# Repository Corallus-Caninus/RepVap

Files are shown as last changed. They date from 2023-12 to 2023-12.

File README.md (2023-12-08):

# RepVap
A *majority* 3D printed evaporative cooler.


A RepVap made with a 5 Gallon bucket cooling a B550M plus motherboard chipset and ryzen 3600 clocked at 4650MHz all cores as a daily workstation.

This project is currently under active development. If you need assistance or would like to purchase a kit with all the parts included (assembly required) email me at ward.joshua92@yahoo.com.

requires OpenSCAD and python3 as well as solidpython.
essentially on ubuntu:

apt install openscad

apt install python3

pip install solidpython

Each folder contains a configuration file and a python file. Set the values in the configuration.toml then 
run the python program to generate your STls. A guide on building a RepVap out of a 5 gallon bucket is 
under development.

Suggested Slicing:

It is recommended to print with adaptive layering with tree supports only touching the bed to allow for precision on the print where needed.
These models were sliced in Cura.

# INLET FLANGE
Print standing up so the grooves are printed along the z axis.

# NOZZLE ARRAY
Print with adaptive layering and a low layer height. Reduce the layer width slightly (ex: 0.35mm on 0.4mm diameter nozzle)
nozzles should be touching the bed, this makes the pagoda cones a little difficult (adaptive layering helps) but yields better nozzles.

# WATER BRACKET

Print with the screw mounts touching the bed. Ensure good overlap with infill so the screw mounts dont seperate when threaded through.

RepVap is a high flow water chiller for cheap aluminum cooling blocks. Its intended use is for 
CPUs and the design is made to be very affordable (~$100 for all the bells and whistles).

RepVap is designed with SolidPython an OpenSCAD wrapper. All designs are parametric such that any container 
could be used (A gable fan on a large trash bin is not out of the question). All variations of the design can be changed in the respective configuration files for different 
motherboards or applications.

Bill of Materials: 
      https://docs.google.com/spreadsheets/d/1tjXMvY8Ov9ljX92phIoySIcV0aM8psuqZ-wuVCSjxi4/edit?usp=sharing
      
My initial prototype:
      https://docs.google.com/spreadsheets/d/1ESvuHrNF-DnBGYz-8B5h_lNTvHFGtqw5J4fCP3uyhEo/edit?usp=sharing

I also recommend the following Youtube videos:

      desertsun02's videos on DIY evaporative cooling.

      Major Hardware's video on 3d printed evaporative coolers and PC water cooling loops.

NOTE: RepVap cannot print itself. the name is simply an omage to the amazing RepRap project and the culture of 
      innovation therein.

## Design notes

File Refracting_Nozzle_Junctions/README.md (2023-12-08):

this allows for a smaller, and historically easier to install nozzle but is much less efficient and
is unmaintained for now but kept for posterity.
Nozzle junctions allow for inline parallel distribution to different cooling plates but is so far 
unnecessary as a large sequential loop from the bucket has been sufficient emperically.

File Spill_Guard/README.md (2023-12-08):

This is @DEPRECATED in favour of Inlets but they look cool and lose less pressure. can be flex sealed to work.

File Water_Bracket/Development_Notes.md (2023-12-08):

# FUTURE FEATURES 
Consider multiple brackets joined by a ceiling underneath the VRM/Screw pillars to cool GPU and 
CPU in laptops. This requires a list of list of screws and of mounts.
ListOfLists: chips, screws, VRMs

Create buckets/splash-guards about the nozzles to fill/guide any
leakage away from motherboard by the tubing. 

Create an upside down motherboard riser.

Create hardshell tubing and integrate into bucket/splash guard guides.

Can use a pressure sensor on the plumbing to indicate a leak which can set a buzzer alarm that turns
off pump or the buckets can just fill if not set upside down. alarm should exist anyways on any 
hydro-electric system that isnt >IPX2 rated.

# RESEARCH
How can SCAD use the power of programming (encapsulation abstraction etc) to make ubiquitous models. 
Why aren't there more libraries for ease of use that would catch up to ease of GUI CAD programs?
Could a graphical programming interface (vr/ar) make this intuitive? (with 3D render feedback in VR)?
could use autocomplete AI for writting libraries called in a node-red manner but build with graphical
programming in mind (making it more intuitive to use more advanced programatic features such as encapsulation)
    node-red tree is CSG tree but can be functionally abstract

A GUI that creates all 3D print files(Block Harness, VRM Connection Harness, Board Risers),
SVGs and a step by step guide on how-to put together the water cooling solution.
This can be seperate from evaporative cooler since people run water coolers with
pickle jars and radiators for 30 bucks.
REQUIRES: 3d printer, printer (optional), measuring device (preferably calipers),
            separate windows machine.

Automatically upload to database user configurations of MOBOS/PCBs that have been measured for browsing
by other users? a "report feedback" that can be moderated by verifying picture measurements.
(way too advanced for now). search locally downloaded configurations by PC/motherboard before
having to measure yourself.

Build hard shell tubing for the flex hoses as a seperate parametric design that takes in 
an SVG for routing.

create connections (linearly slanted not 90 degree) that can be lamenated/glued with aluminum
foil to VRMs using extracted code from screw terminals to precisely connect top of heat sink
to VRMs and reduce shorting chance. diagonalize pillars. use svg idea to create a stencil
printout for aluminum or just print out dimensions. This feature depends on the capability
of the target audience.

these should be in a simple tkinter gui .exe bundled with OpenSCAD(mac and linux can run source)
with instruction images on one side and entry fields on the other to reduce
some of the parameter overhead. produce SVG and .obj files in respective folders for printing.

built in photogrammetry using pictures of motherboards and clicking on water block
corners (dimensions are entered of water block to give ground truthing) then screw terminals in GUI
to generate [x,y,z] coordinate params. Use pillow and instruct user to 
planar translate the camera. find some closed loop metric to say if image photogrammetry
failed to prevent false positive prints, possibly comparing ground truth dimensions (user clickes)
with raw photogrammetric dimensions using k-folds validation about each corner
(permute 2*4! comparisons for all (x,y) pairs) use edge detection filtering (DOG) since aluminum
or colored block is same color to find each raw corner coordinate. Note that aluminum block must
be solid color for measurements in instructions and glares will effect the quality
(a healthy dousing of flour would suffice, just like laser scanning photogrammetry from high school)
use a error tolerance in photogrammetry set based on plasticity of plastic leaf-spring behaviour. find this
empirically it isnt too important, if nothing else just make sure its rigid with little-no plasticity 
and precise.

average the user clicks on each 2 points to account for non-pixel-perfect clicking s.t. x1 x2 are equal
for top points (x = (x1 + x2)/2) since is a parallelogram.
make user reclick if distance between x1 and x2 > some tolerance.
reject the photogrammetry if k-folds is below some tolerance.

This is too ambitious. would be easy with a team or another person but more features can be done
with less effort.

should extract pillars to create standoffs for laptops or other motherboards
should be implemented in a related project this also helps prevent any potential leakage damage.

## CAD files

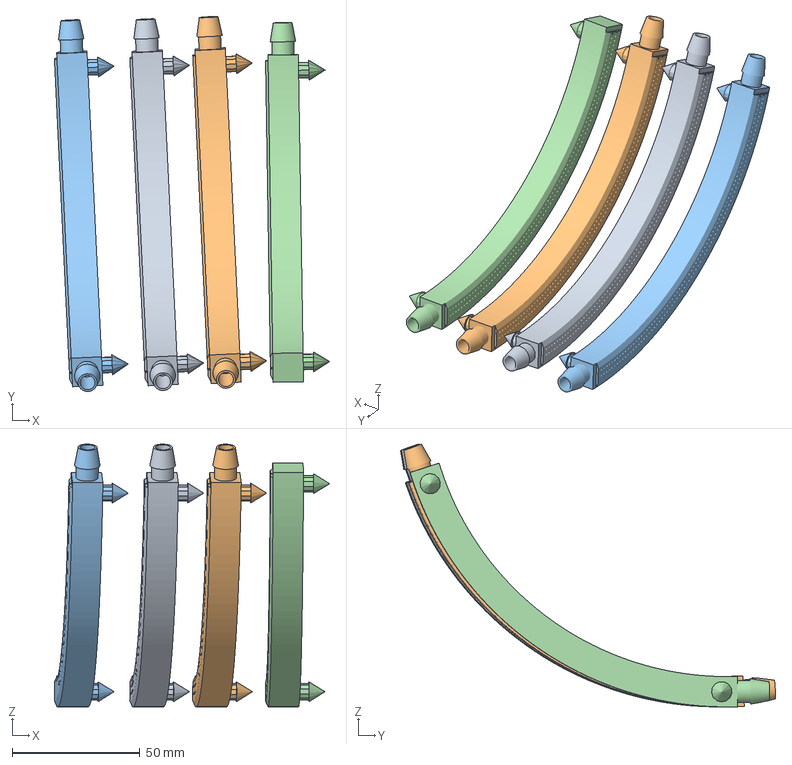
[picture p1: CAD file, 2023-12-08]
Nozzle_Array/FQ5_x4__nozzle_arc2.3mf
107.9 x 147.0 x 103.0 mm
x4__nozzle_arc2.stl
x4__nozzle_arc2.stl(1)
x4__nozzle_arc2.stl(2)
ENDCAP_x1_nozzle_arc2.stl

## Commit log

2020-12-24 minor refactors and cleanup
    [ENDCAP_x1_nozzle_arc1.scad, ENDCAP_x1_nozzle_arc1.stl, x3__nozzle_arc0.scad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]
2020-12-26 correct shroud on Spill_Guard with various minor patches
    [gutter.scad, gutter.stl]
2020-12-26 ensure shroud drains into catch
    [gutter.scad, gutter.stl]
2020-12-27 init reservoir bottle stand
    [bottle_stand.scad, bottle_stand.stl]
2020-12-27 init tkinter gui
    [mount.scad, mount.stl]
2020-12-27 patch spout tearing
    [gutter.scad, gutter.stl]
2020-12-28 tighten up lower radius of shroud
    [gutter.scad, gutter.stl]
2020-12-28 increase spout height to reduce cavity and patch surface seam
    [gutter.scad, gutter.stl]
2020-12-29 create bottle tripod stand for siphon based reservoir
    [bottle_stand.scad, bottle_stand.stl, x3_bottle_stand_leg.scad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]
2020-12-29 minor temporary patch to solve seams in STL
    [bottle_stand.scad, bottle_stand.stl, x3_bottle_stand_leg.scad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]
2020-12-30 add cone to affix tubes (pagoda nozzle?)
    [ENDCAP_x1_nozzle_arc1.scad, ENDCAP_x1_nozzle_arc1.stl, x3__nozzle_arc0.scad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]
2020-12-30 remove threads
    [bottle_stand.scad, bottle_stand.stl, x3_bottle_stand_leg.scad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]
2021-07-08 initial inline carbon filter
2021-07-23 add container slope since most containers are mold injected
2021-10-02 add clean script to remove .stl and .scad files from previous render
2021-10-02 major cleanup, final rework for Nozzle_Array to fit under lid and Inlet_Flange (also both are now snap on fastener). add clean and render helper files to somewhat assist newcomers.
    [ENDCAP_x1_nozzle_arc1.scad, ENDCAP_x1_nozzle_arc1.stl, ball.scad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]
2021-10-07 initial pagoda fasteners for through hole screwless mounts
2021-10-07 add water mount to render targets
2021-11-02 add configuration for z offset in screw terminals (project: Al cooling cube)
2021-11-10 add: update water bracket configuration for AM4 (and project AL)
2021-11-10 add: init powershell scripts
2021-11-10 fix: documentation for tmp powershell script
2022-01-14 add: archive configuration for working AM4 bracket
2022-01-31 add: remove symmetry to solve track alignment on array partition
2022-04-01 fix: printable default configuration and number of arrays
2022-05-13 fix: nozzle_array nozzle spacing
2022-05-14 fix: Nozzle offset
2022-05-15 add: format and allow nozzle spacing along track to be configured
2022-06-04 delete: tube linkage
2023-12-08 im so sorry
    [FQ5_x4__nozzle_arc2.3mf]
2025-09-30 feat: Implement slot-based segment connections for modular spray rig
2025-09-30 refactor: Remove deprecated interconnects, consolidate slotting, fix assertion
2025-09-30 fix: Fix syntax error in nozzle diameter assertion
2025-10-01 feat: Implement side slot interconnects for spray rig segments
2025-10-01 fix: Address SyntaxError in nozzle parameter definition
2025-10-01 fix: Resolve SyntaxError from comment after line continuation; remove duplicate nozzle params
2025-10-01 fix: Remove background flag from OpenSCAD calls for STL generation
2025-10-01 fix: Correct positioning of male and female interconnect slots
2025-10-01 fix: Correct interconnect slot geometry, sizing, and centering
2025-10-02 refactor: Adjust interconnect slot height calculation and expressions
2025-10-02 fix: Add fastener holes to interconnect slots and correct slot height
2025-11-21 Fix: Water Bracket opening render artifact
2025-11-29 Add: updated config for the current MI25 target
2025-12-05 FIX: (untested) update values for 5 gallon bucket to attempt to fix the perfect circle error
2025-12-05 Add: extract interconnect and fix various artifacts, also maximize nozzle array for all spaces internal to the bucket lip
2025-12-05 Fix: lip hinge alignment
2025-12-10 Add: intake nozzle for the Spray Rig with Interconnects.
2025-12-10 Configure: fat tube for max flow from dedicated rig pump
2025-12-10 Fix: ensure the pagoda nozzle intake is fit exactly
2026-05-10 Add: prototype offset to prevent lip leakage
2026-05-23 Init: Spray_Array, a Spray_Rig for attaching to the bottom of the lid like Nozzle_Array to prevent leaks (you get the best of both worlds)
2026-05-23 Init: Stencil for drilling Spray_Array to lids
